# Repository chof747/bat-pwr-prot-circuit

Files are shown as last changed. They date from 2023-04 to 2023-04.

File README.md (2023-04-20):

# Battery Protection Circuit

Taken from  Great Scott's Design only the protection part + added simple down-regulation of voltage for 3v3 circuits.

The circuit is intended to work with the following circuit:
https://github.com/chof747/battery-holder-hardware

It contains the following elements:

 - FS312F-G LiIon protection circut
 - Mosfets to trigger the charging and discharging
 - A ME6211C33M5G 3v3 low dropout voltage regulator
 - Pinouts for to be placed on a breadboard as power supply
 - Pinouts to connect the charging circuit and the battery

## Todo

Requires confirmation if this setup is working

## Revision History:

 - **v1.0**: Initial Version (filed for fabrication: 04.12.2022, successfully assembled 15.02.2023)
 - **v1.1**: First revision with seperated Bat+ and 3v3 line (filed for fabrication 19.04.2023)

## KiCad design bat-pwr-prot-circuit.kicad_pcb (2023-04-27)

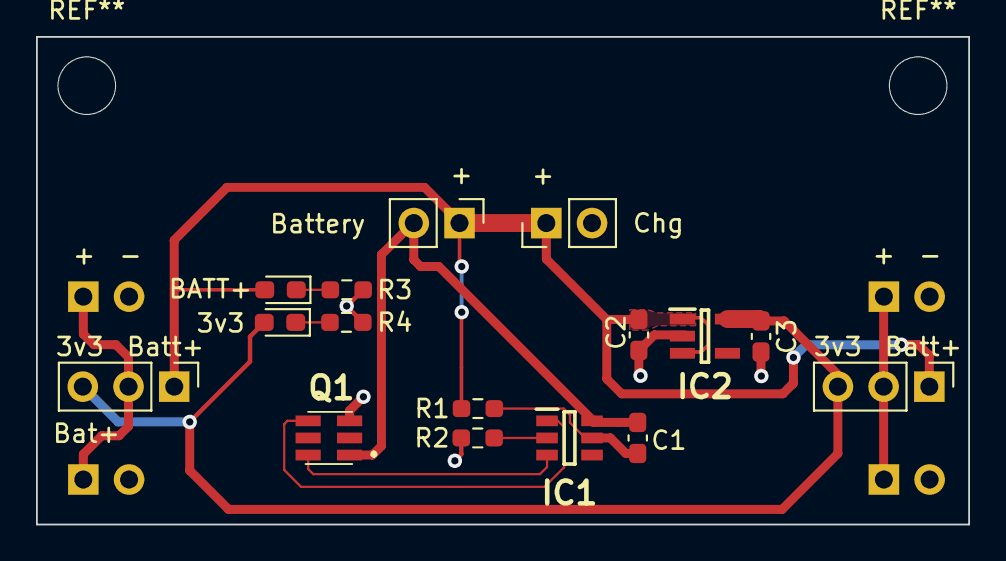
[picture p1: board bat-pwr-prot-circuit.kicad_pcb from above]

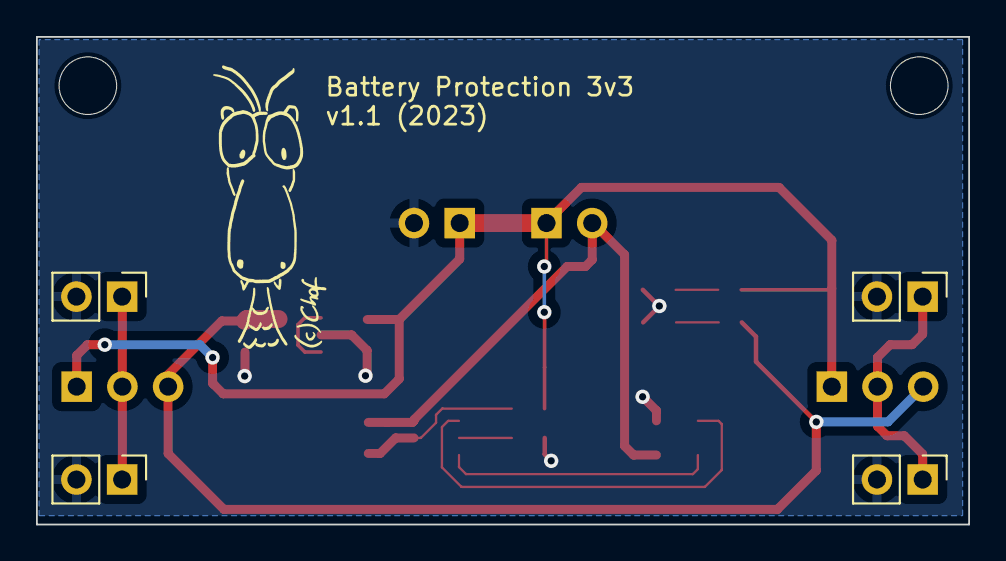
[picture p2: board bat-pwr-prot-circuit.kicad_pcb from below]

Board: 2 copper layers, 51.8 x 27.1 mm, 20 parts (4 on the bottom side), 12 nets.

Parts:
C1: 0.1uF; C_0603_1608Metric_Pad1.08x0.95mm_HandSolder
C2, C3: 1uF; C_0603_1608Metric_Pad1.08x0.95mm_HandSolder
D1: BATT+; LED_0603_1608Metric_Pad1.05x0.95mm_HandSolder
D2: 3v3; LED_0603_1608Metric_Pad1.05x0.95mm_HandSolder
IC1: FS312F-G; SOT95P280X145-6N
IC2: 3v3 Regulator; SOT95P270X145-5N
J1, J4: Bat+; PinHeader_1x02_P2.54mm_Vertical
J2, J5: 3v3; PinHeader_1x02_P2.54mm_Vertical
J3: Battery; PinHeader_1x02_P2.54mm_Vertical
J6: Chg; PinHeader_1x02_P2.54mm_Vertical
JL1: Conn_01x03; PinHeader_1x03_P2.54mm_Vertical
JR1: Conn_01x03; PinHeader_1x03_P2.54mm_Vertical
Q1: FS8205
R1: 100; R_0603_1608Metric_Pad0.98x0.95mm_HandSolder
R2: 2k; R_0603_1608Metric_Pad0.98x0.95mm_HandSolder
R3, R4: 680; R_0603_1608Metric_Pad0.98x0.95mm_HandSolder

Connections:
+3V3: C3.1, D2.2 (A), IC2.5 (VOUT), JL1.3, JR1.3
/BATT+: C2.1, D1.2 (A), IC2.1 (VIN), IC2.3 (CE), J3.1, J6.1, JL1.1, JR1.1, R1.2
/BATT-: C1.2, IC1.6 (GND), J3.2, Q1.1 (S1)
/Left: J1.1, J4.1, JL1.2
/Right: J2.1, J5.1, JR1.2
/VCC: C1.1, IC1.5 (VCC), R1.1
GND: C2.2, C3.2, IC2.2 (VSS), J1.2, J2.2, J4.2, J5.2, J6.2, Q1.3 (S2), R2.2, R3.2, R4.2
unnamed: D1.1 (K), R3.1
unnamed: D2.1 (K), R4.1
unnamed: IC1.1 (OD), Q1.6 (G1)
unnamed: IC1.2 (CS), R2.1
unnamed: IC1.3 (OC), Q1.4 (G2)

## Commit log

2022-12-04 Revision one - with double mosfet
    [bat-pwr-prot-circuit.kicad_pcb, bat-pwr-prot-circuit.kicad_sch, template-project.kicad_pcb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]
2023-02-16 Selectable rails and led indicators
    - Added pin selectory to configure the left and right rail connectors individually for batt+ and 3v3
    - Added led indicators for batt+ and 3v3
    [bat-pwr-prot-circuit.kicad_pcb, bat-pwr-prot-circuit.kicad_sch]
2023-04-20 Revision 1.1 commit
    - Separated power lines to Bat+ and 3v3
    - Added selector pins for each side of the board
    - Added mounting holes
    - Improved the labeling on the front
    - Added logo
    [bat-pwr-prot-circuit.kicad_pcb]
2023-04-27 Updated template for KiCAD 7
    [bat-pwr-prot-circuit.kicad_pcb, bat-pwr-prot-circuit.kicad_sch]
2023-09-30 modified .gitignore to leave out bom html
2024-07-18 Updated footprints to kicad8
    [bat-pwr-prot-circuit.kicad_sch]
